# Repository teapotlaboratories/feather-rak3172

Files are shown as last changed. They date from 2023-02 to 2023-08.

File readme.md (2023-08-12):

# Teapotlabs Feather RAK3172
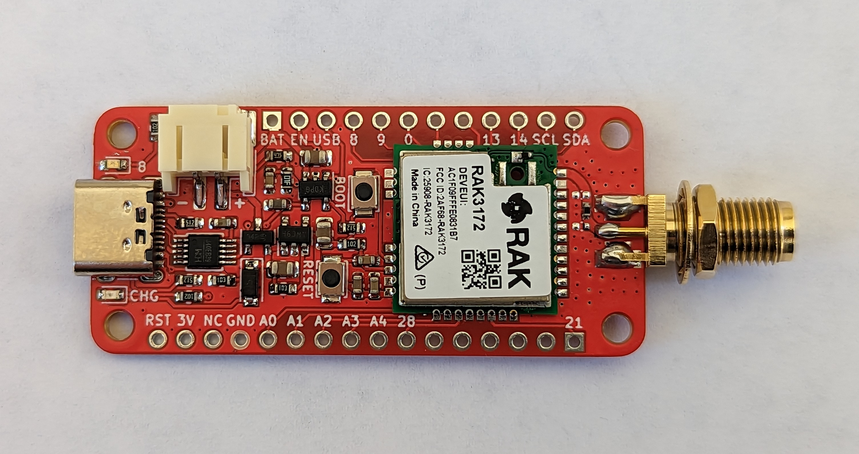
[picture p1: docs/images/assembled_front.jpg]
 
 
Teapotlabs Feather RAK3172 a Low-cost, Low-power LoRaWAN development board that breaks out [RAKwireless RAK3172](https://docs.rakwireless.com/Product-Categories/WisDuo/RAK3172-Module/Datasheet) to an Adafruit Feather-compatible format.

Based on the RAK3172, a STM32WLE5CC based module with ARM Cortex M4 processor, 48 MHz and 3.3V logic. The chip has a 256K of flash and 64K of RAM. 
With low-power application in mind, the board is capable to be in sleep mode for as low as 11uA, it also has a built-in voltage divider to sense battery voltage and battery charger.

Teapotlabs Feather RAK3172 is heavily inspired by [Penguino STM32WL LoRa-E5](https://github.com/azerimaker/Penguino-STM32WL-LoRa-E5) and [BastWAN-WLE](https://github.com/ElectronicCats/BastWAN-WLE) projects!

## Specification

- [RAK3172](https://docs.rakwireless.com/Product-Categories/WisDuo/RAK3172-Module/Overview/): An STM32WLE5CC module
- 3.3V only power/pin. 
- Down to 11uA Deep-Sleep
- Switchable TX Power. 14 dBm or 22 dBm on 915MHz frequency
- Supports LoRaWAN 1.0.3
- USB-C for **Arduino** and  **Mbed OS/STM32Cube** programming
- SMA antenna connector 
- JST-PH 2-Pin Battery Connector
- Built-in LiPo Charger ( 200mA Charge Rate )
- Voltage-Divider for Battery Monitoring ( default: **disabled** )
- LED Indicator on pin 8 ( default: **disabled** )
- Compatible with many Adafruit FeatherWings
- Max 1A power output

## To-do
- Update assembly/TeapotFeatherRAK3172_Assembly.zip and docs file to Revision 9.1

## Schematics
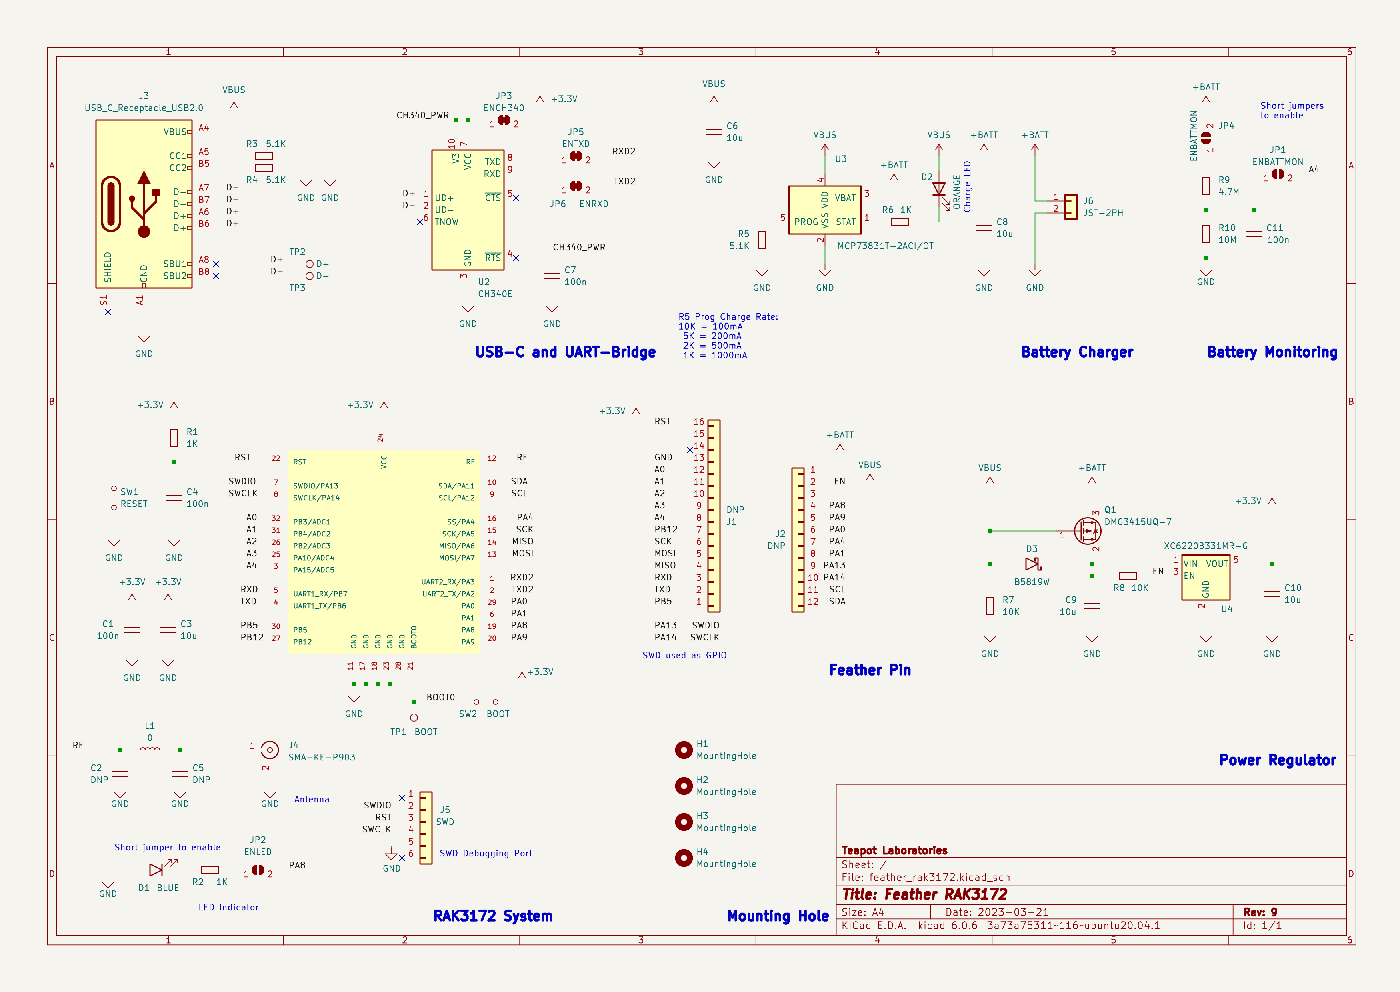
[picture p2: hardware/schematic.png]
schematic


### Jumper Definition
- JP1 and JP4: Enable/Disable Voltage Divider for Battery Sensing
- JP2: Enable/Disable LED Indicator on Pin 8
- JP3, JP5, and JP6: Enable/Disable UART Bridge

### Revision
- Revision 9  : First public release
- Revision 9.1: Fix LED D1 polarity 

### Pinout Diagram
> :warning: **The following pinout is not complete, please see STM32WLE5CC datasheet for more details.** 
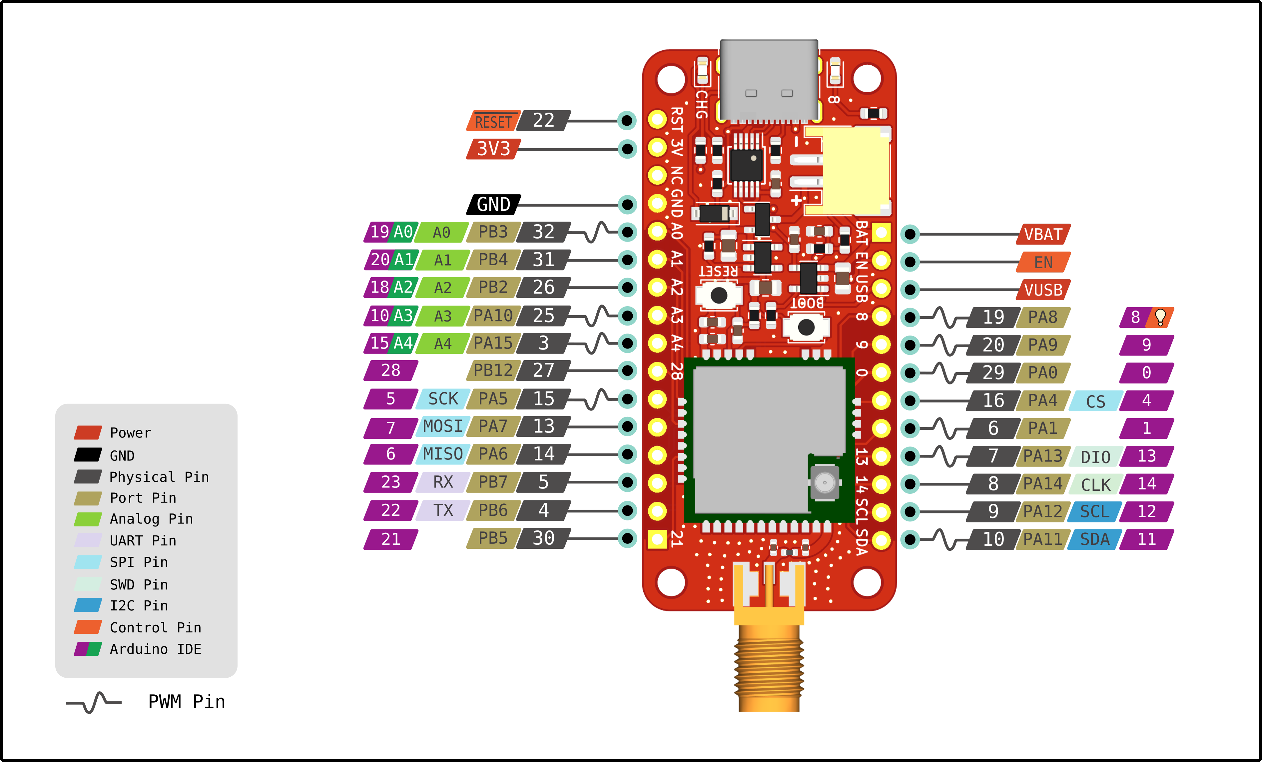
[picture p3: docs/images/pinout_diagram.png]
pinout_diagram


## Board
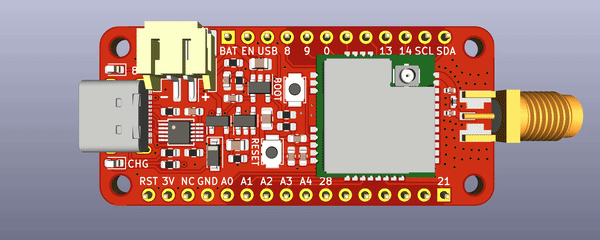
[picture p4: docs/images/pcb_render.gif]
pcb_render
<p align="center">  <br><b>PCB Render</b></p>

Built using KiCAD, the board is design to be as small as possible. The following design are based on the latest revision.
| Top Board | Bottom Board |
|--|--|
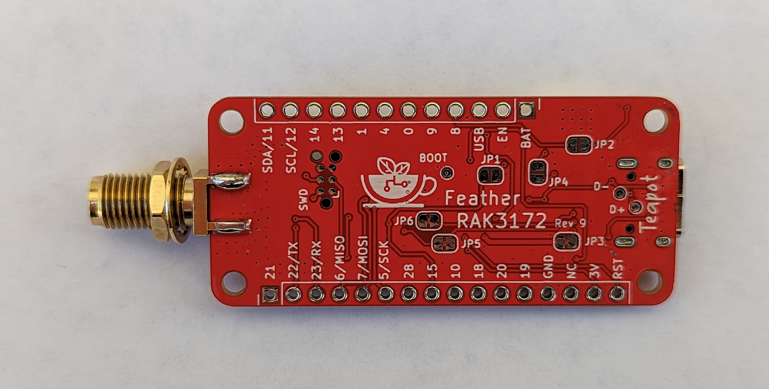
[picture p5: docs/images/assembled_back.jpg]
assembled_back
| <p align="center"> assembled_front</p> |  |
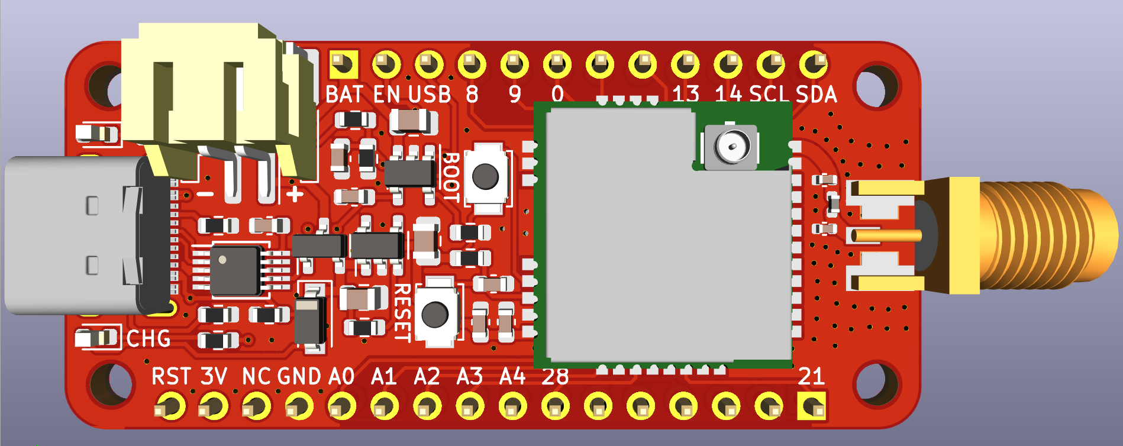
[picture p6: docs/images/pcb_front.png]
pcb_front
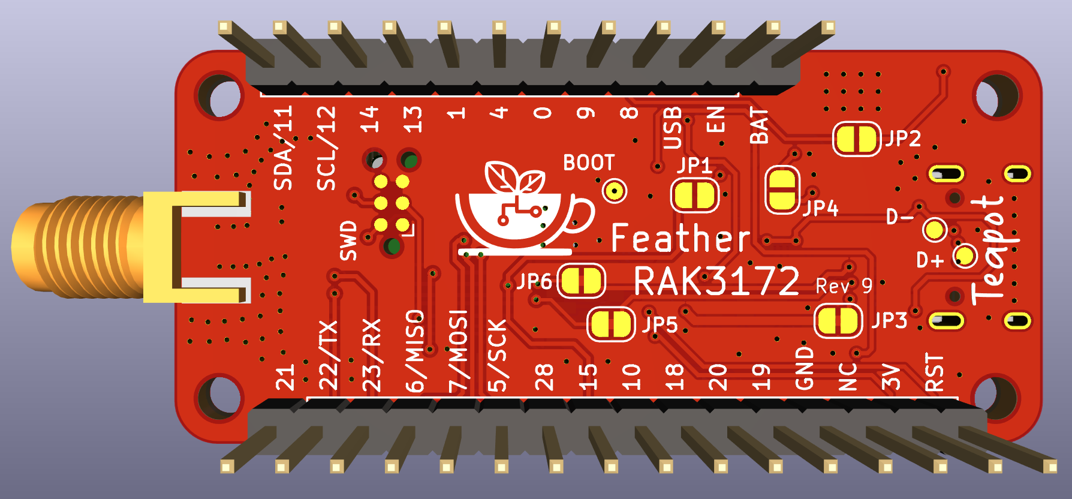
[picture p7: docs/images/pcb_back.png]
pcb_bottom
|  |  |

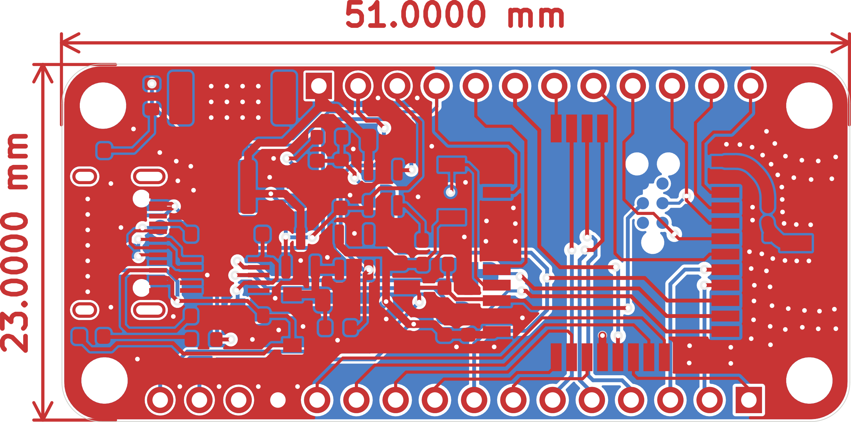
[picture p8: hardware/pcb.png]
pcb
 <p align="center"> <br><b>PCB Top and Bottom Layout</b></p> 
  
### Case
<p align="center">  case_render</p>

The case is design by [atmakers](https://www.thingiverse.com/atmakers/designs) with **Attribution-ShareAlike 3.0 Unported (CC BY-SA 3.0)** license.
The cases are 3D printable with any generic 3D printer with/without suppport (depends on the orientation). The STL files are available from authors download page  [here](https://www.thingiverse.com/thing:3212895) or from [this](https://github.com/teapotlaboratories/feather-rak3172/tree/main/hardware/case) repo.
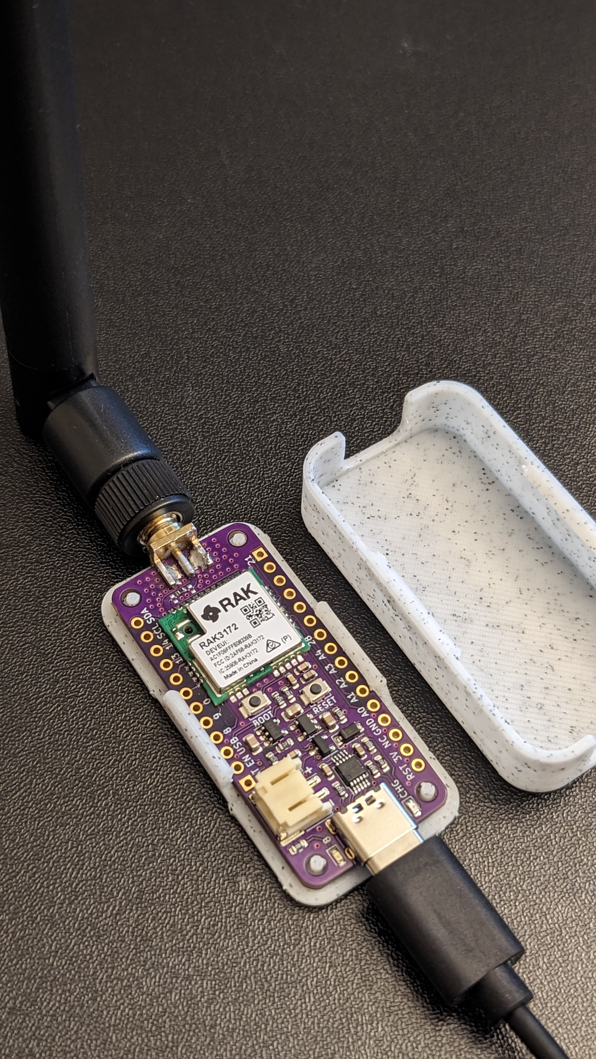
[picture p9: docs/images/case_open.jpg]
 <p align="center"><br><b>Case Open</b></p>
 
### Measurement
Power consumption measured using [Nordic PPK2](https://www.nordicsemi.com/Products/Development-hardware/Power-Profiler-Kit-2). The following are the summary of the measurement:
- Sleep and all jumper disabled (JP1 - JP6): **10.44 uA**
- Sleep and UART-Bridge enabled ( JP3, JP5, and JP6 ): **23.76 uA**
- Sleep, UART-Bridge and Battery Sense enabled ( JP1, and JP3 - JP6 ): **25.41 uA** 
- Transmit at 14 dBm: **40.45 mA**
- Transmit at 20 dBm: **100.38 mA**

More detailed measurement can be found [here](https://github.com/teapotlaboratories/feather-rak3172/tree/main/docs/measurement)

### Bill Of Materials
Most of the components are generic and can be bought from any electornics/semi-conductor distributor. RAK3172 is the only component available in [RAKwireless store](https://store.rakwireless.com/products/wisduo-lpwan-module-rak3172?variant=40014759493830). The bill of materials can be downloaded [here](https://github.com/teapotlaboratories/feather-rak3172/raw/main/hardware/bill_of_materials.csv)

> :warning: **Be sure to buy the RAK3172 variant without IPEX to use SMA connector** 

|Id|Designator|Quantity|Value|Footprint|
|:----|:----|:----|:----|:----|
|1|C11,C7,C4,C1|4|100n|0603_1608Metric|
|2|C6,C3|2|10u|0603_1608Metric|
|3|C9,C8,C10|3|10u|0805_2012Metric|
|4|D1|1|BLUE|0603_1608Metric|
|5|D2|1|ORANGE|0603_1608Metric|
|6|D3|1|B5819W|SOD-123|
|7|J3|1|U262-161N-4BVC11|USB_C_Receptacle_XKB_U262-16XN-4BVC11|
|8|J4|1|SMA-KE-P903|SMA-KE-P903|
|9|J6|1|S2B-PH-SM4-TB|JST_PH_S2B-PH-SM4-TB_1x02-1MP_P2.00mm_Horizontal|
|10|L1|1|0|0402_1005Metric|
|11|Q1|1|DMG3415UQ-7|SOT-23|
|12|R10|1|10M|0603_1608Metric|
|13|R2,R6,R1|3|1k|0603_1608Metric|
|14|R3,R5,R4|3|5.1k|0603_1608Metric|
|15|R7,R8|2|10k|0603_1608Metric|
|16|R9|1|4.7M|0603_1608Metric|
|17|SW1|1|B3U-1000P|SW_SPST_B3U-1000P|
|18|SW2|1|B3U-1000P|SW_SPST_B3U-1000P|
|19|U1|1|RAK3172|RAK3172|
|20|U2|1|CH340E|MSOP-10_3x3mm_P0.5mm|
|21|U3|1|MCP73831T-2ACI/OT|SOT-23-5|
|22|U4|1|XC6220B331MR-G|SOT-23-5|
|23|C5,C2|2|DNP|0402_1005Metric|
|24|J2|1|DNP|PinHeader_1x12_P2.54mm_Vertical|
|25|J1|1|DNP|PinHeader_1x16_P2.54mm_Vertical|

## Programming

By default, programming the device can be done over  the **USB-C**. Internally, the USB-C connects to the UART-Bridge that connects to the **UART2** port of the RAK3172. Out of the factory, the RAK3172 chip ships with an **AT firmware** that can be tested by sending AT command via the USB-C.

Using the USB-C, user can program the board using the **Arduino** or **MbedOS/STM32Cube** SDK.
The following are some very good tutorial to start developing with the device:
 - [Communicating with the AT firmware](https://docs.rakwireless.com/Product-Categories/WisDuo/RAK3172-Module/Quickstart/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)
 - [Programming with Arduino](https://docs.rakwireless.com/Product-Categories/WisDuo/RAK3172-Module/Quickstart/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)
 - [Programming with STM32Cube](https://docs.rakwireless.com/Product-Categories/WisDuo/RAK3172-Module/Low-Level-Development/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)
	 - RAKDAP1 is not needed. Before connecting to **STM32CubeProgrammer**, hold `BOOT` and press `RESET` on the board, to boot to UART bootloader of the RAK3172. After `RESET` button is pressed, `BOOT` button can be released, and the board should be able to connect to the **STM32CubeProgrammer**
 - [Programming with MbedOS](https://github.com/hallard/LoRa-E5-Tiny/blob/main/README.md#compile-and-flash-firmware)
	 - Programming the board can be done **without** using the ST-LINK, it should be simillar to [Programming with STM32Cube](https://docs.rakwireless.com/Product-Categories/WisDuo/RAK3172-Module/Low-Level-Development/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) process.

## Example Project
Teapotlabs Feather RAK3172 is a feather compatible board, and hence is compatible with the many available FeatherWing. The following are some example project that uses FeatherWings.

### Over-engineered Clock 
An over-engineered clock with main purpose to showcase FeatherWings compatibility.
FeatherWings and sensors used:  
- [Ultimate GPS](adafruit.com/product/3133)  
- [Tri-Color E-Ink](adafruit.com/product/4814)  
- [Qwiic Shield](sparkfun.com/products/16790)  
- [BME680](adafruit.com/product/3660)  
- [Modified E-Ink Case](learn.adafruit.com/eink-featherwing-display-stand)

<p align="center">
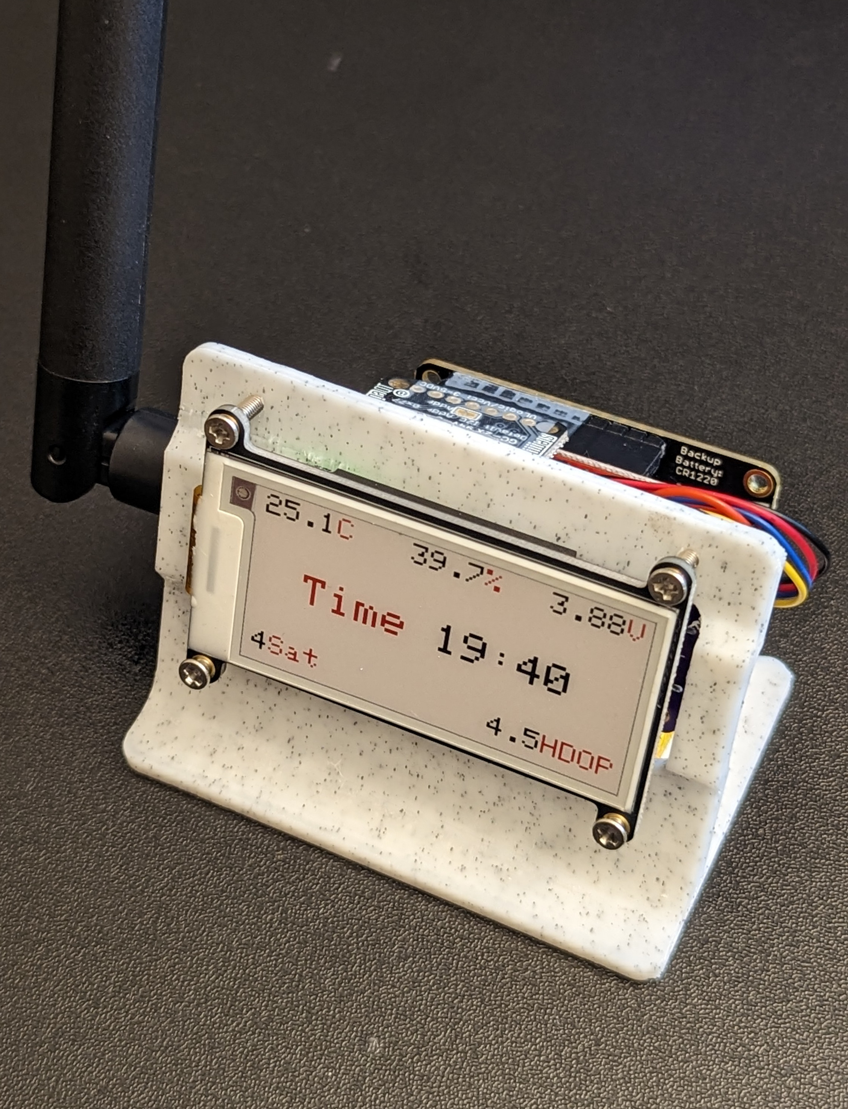
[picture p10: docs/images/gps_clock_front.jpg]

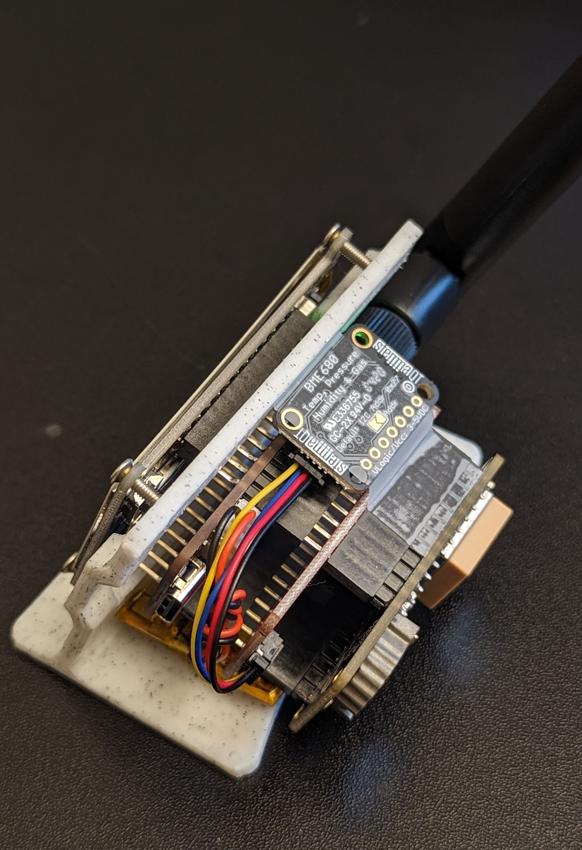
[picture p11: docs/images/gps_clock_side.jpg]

<br><b>Front and Side View</b></p>

<p align="center">  
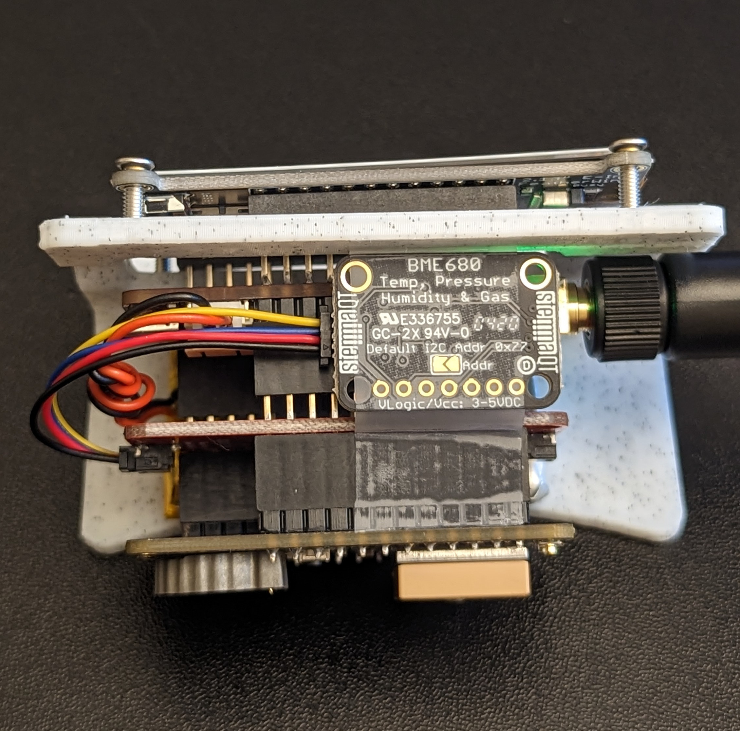
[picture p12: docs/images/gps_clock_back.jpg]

<br><b>Back View</b>
</p>
 
## Reference
The project won't be possible without the amazing work from people across the globe. The following are the reference to those awesome projects:

 - [Adafruit Feather RP2040](https://github.com/adafruit/Adafruit-Feather-RP2040-PCB)
 - [Penguino STM32WL LoRa-E5](https://github.com/azerimaker/Penguino-STM32WL-LoRa-E5)
 - [BastWAN-WLE](https://github.com/ElectronicCats/BastWAN-WLE)

## License
The product is open-source! However, some part of library used under **src**, might have it's own license.
Please reach out or create a ticket to report any license violation.



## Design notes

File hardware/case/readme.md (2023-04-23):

# License
The case are design by [atmakers](https://www.thingiverse.com/atmakers/designs) with **Attribution-ShareAlike 3.0 Unported (CC BY-SA 3.0)** license.
Original link: https://www.thingiverse.com/thing:3212895



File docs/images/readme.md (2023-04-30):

# Images

## Assembled Back


## Assembled Back Purple
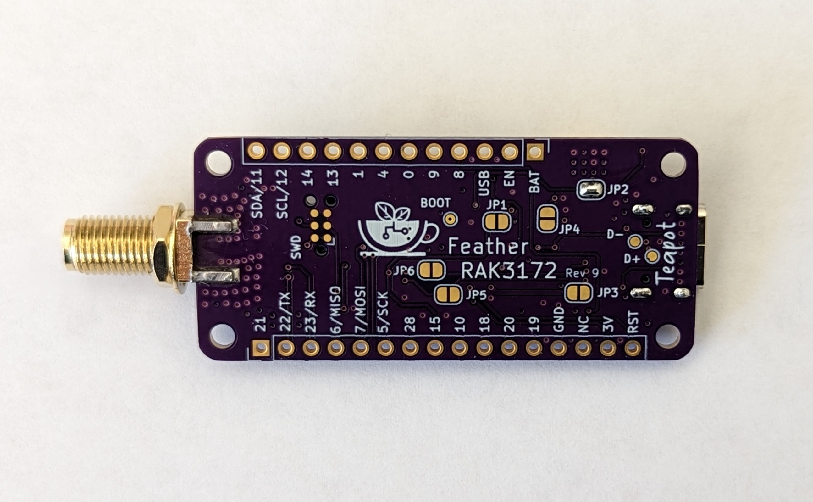
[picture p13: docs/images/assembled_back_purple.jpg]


## Assembled Front


## Assembled Front Purple
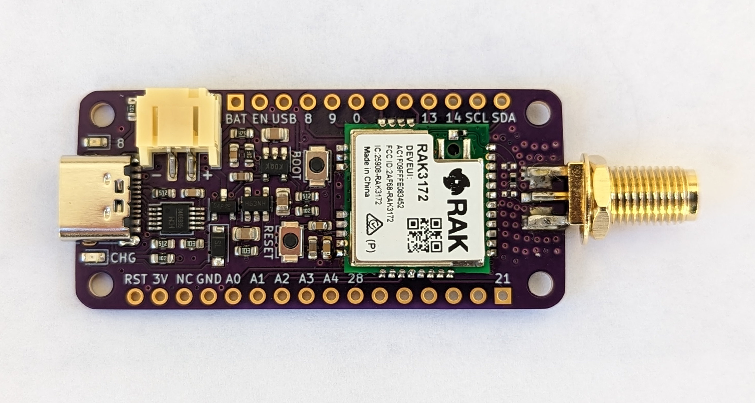
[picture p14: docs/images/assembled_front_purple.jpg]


## Case Close
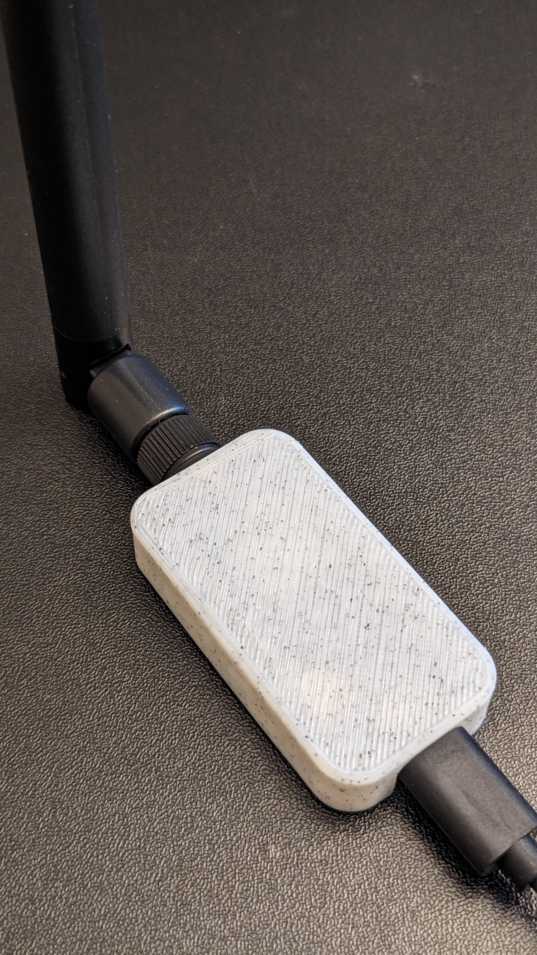
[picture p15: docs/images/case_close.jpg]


## Case Open


## Case Render


## GPS Clock Back


## GPS Clock Front


## GPS Clock Side


## PCB Back


## PCB Front


## PCB Front Orthographic
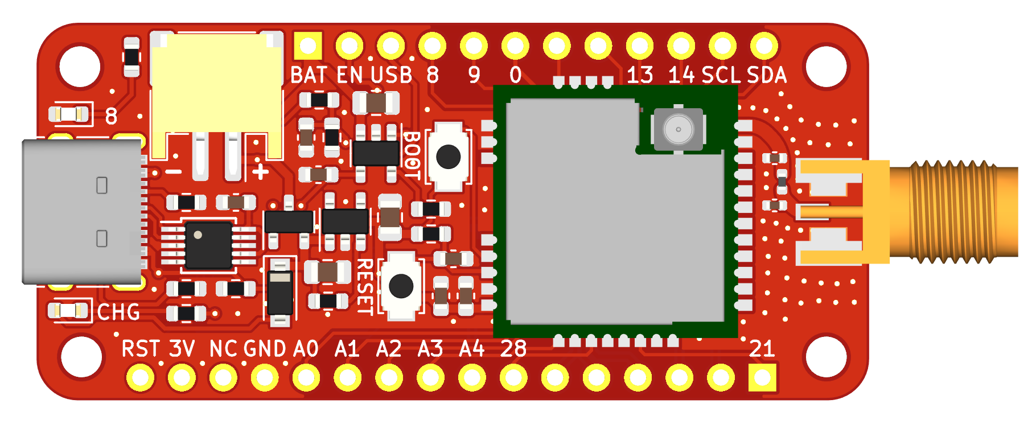
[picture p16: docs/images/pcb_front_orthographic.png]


## PCB Render


## Pinout Diagram


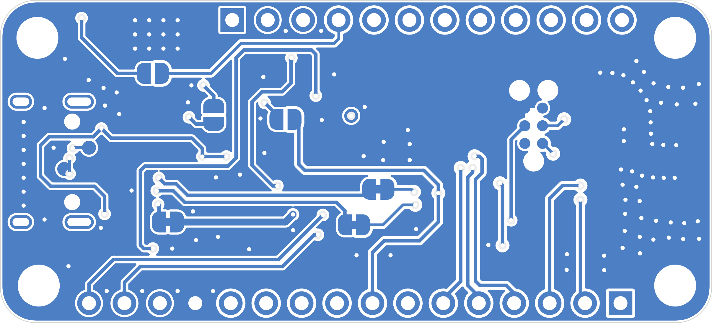
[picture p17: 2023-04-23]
hardware/pcb_bottom.png

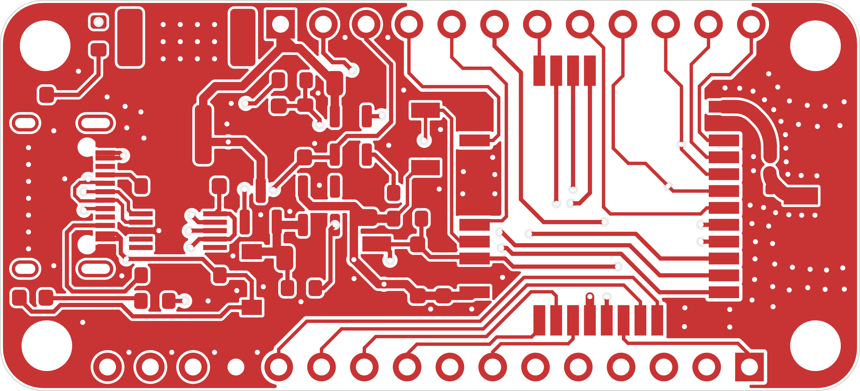
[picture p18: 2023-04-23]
hardware/pcb_top.png

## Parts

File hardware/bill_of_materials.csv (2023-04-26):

Id | Designator | Quantity | Manufacturer | Manufacturer Part Number | Value | Description | Footprint | Type | Distributor | Distributor Part Number | Distributor Link
1 | C11,C7,C4,C1 | 4 | YAGEO | CC0603KRX7R6BB104 | 100n | Ceramic Capacitor 100n 10% 10V X7R | 0603_1608Metric | SMD | LCSC | C519438 | https://www.lcsc.com/product-detail/_YAGEO-_C519438.html
2 | C6,C3 | 2 | Samsung Electro-Mechanics | CL10A106KP8NNNC | 10u | Ceramic Capacitor 10u 10% 10V X5R | 0603_1608Metric | SMD | LCSC | C19702 | https://www.lcsc.com/product-detail/_Samsung-Electro-Mechanics-_C19702.html
3 | C9,C8,C10 | 3 | Samsung Electro-Mechanics | CL21A106KPFNNNE | 10u | Ceramic Capacitor 10u 10% 10V X5R | 0805_2012Metric | SMD | LCSC | C17024 | https://www.lcsc.com/product-detail/_Samsung-Electro-Mechanics-_C17024.html
4 | D1 | 1 | Everlight Elec | 19-217/BHC-ZL1M2RY/3T | BLUE | LED Blue 2V 25mA | 0603_1608Metric | SMD | LCSC | C72041 | https://www.lcsc.com/product-detail/_Everlight-Elec-_C72041.html
5 | D2 | 1 | EKINGLUX | E6C0603SEAC1UDA | ORANGE | LED Orange 2V 25mA | 0603_1608Metric | SMD | LCSC | C375450 | https://www.lcsc.com/product-detail/_EKINGLUX-_C375450.html
6 | D3 | 1 | GOODWORK | B5819W | B5819W | Schottky Barrier Diodes (SBD) 40V 0.58V@1A | SOD-123 | SMD | LCSC | C2943878 | https://www.lcsc.com/product-detail/_GOODWORK-_C2943878.html
7 | J3 | 1 | XKB Connectivity | U262-161N-4BVC11 | U262-161N-4BVC11 | USB Type C Receptacle | USB_C_Receptacle_XKB_U262-16XN-4BVC11 | SMD | LCSC | C319148 | https://www.lcsc.com/product-detail/_XKB-Connectivity-_C319148.html
8 | J4 | 1 | DreamLNK | SMA-KE-P903 | SMA-KE-P903 | SMA RF Connectors Board Edge 50Ω 5.35mm 915MHz | SMA-KE-P903 | Through-Hole | LCSC | C914558 | https://www.lcsc.com/product-detail/_DreamLNK-_C914558.html
9 | J6 | 1 | JST Sales America Inc. | S2B-PH-SM4-TB(LF)(SN) | S2B-PH-SM4-TB | Connector Header Right Angle 2 position 0.079" (2.00mm) | JST_PH_S2B-PH-SM4-TB_1x02-1MP_P2.00mm_Horizontal | SMD | LCSC | C295747 | https://www.lcsc.com/product-detail/Wire-To-Board-Wire-To-Wire-Connector_JST-Sales-America-S2B-PH-SM4-TB-LF-SN_C295747.html
10 | L1 | 1 | YAGEO | RC0402JR-070RL | 0 | Resistor 0 5% 65mW | 0402_1005Metric | SMD | LCSC | C60485 | https://www.lcsc.com/product-detail/_YAGEO-_C60485.html
11 | Q1 | 1 | Diodes Incorporated | DMG3415UQ-7 | DMG3415UQ-7 | MOSFET P-Channel 20V 4A 39mΩ@4.5V | SOT-23 | SMD | LCSC | C459537 | https://www.lcsc.com/product-detail/_Diodes-Incorporated-_C459537.html
12 | R10 | 1 | UNI-ROYAL(Uniroyal Elec) | 0603WAF1005T5E | 10M | Resistor 10M 1% 100mW | 0603_1608Metric | SMD | LCSC | C7250 | https://www.lcsc.com/product-detail/_UNI-ROYAL-Uniroyal-Elec-_C7250.html
13 | R2,R6,R1 | 3 | FOJAN | FRC0603J102 TS | 1k | Resistor 1k 5% 100mW | 0603_1608Metric | SMD | LCSC | C2907113 | https://www.lcsc.com/product-detail/_FOJAN-_C2907113.html
14 | R3,R5,R4 | 3 | YAGEO | RC0603FR-075K1L | 5.1k | Resistor 5.1k 1% 100mW | 0603_1608Metric | SMD | LCSC | C105580 | https://www.lcsc.com/product-detail/_YAGEO-_C105580.html
15 | R7,R8 | 2 | YAGEO | RC0603JR-0710KL | 10k | Resistor 10k 5% 100mW | 0603_1608Metric | SMD | LCSC | C99198 | https://www.lcsc.com/product-detail/_YAGEO-_C99198.html
16 | R9 | 1 | UNI-ROYAL(Uniroyal Elec) | 0603WAF4704T5E | 4.7M | Resistor 4.7M 1% 100mW | 0603_1608Metric | SMD | LCSC | C23163 | https://www.lcsc.com/product-detail/_UNI-ROYAL-Uniroyal-Elec-_C23163.html
17 | SW1 | 1 | Omron Electronics | B3U-1000P | B3U-1000P | Tactile Switches SPST 50mA 12V 2.5x3mm | SW_SPST_B3U-1000P | SMD | LCSC | C231329 | https://www.lcsc.com/product-detail/_Omron-Electronics-_C231329.html
18 | SW2 | 1 | Omron Electronics | B3U-1000P | B3U-1000P | Tactile Switches SPST 50mA 12V 2.5x3mm | SW_SPST_B3U-1000P | SMD | LCSC | C231329 | https://www.lcsc.com/product-detail/_Omron-Electronics-_C231329.html
19 | U1 | 1 | RAKwireless | RAK3172 | RAK3172 | RAK3172 Module without IPEX AS923 | RAK3172 | SMD | RAKwireless | 309044 | Contact inquiry@rakwireless.com for SKU: 309044
20 | U2 | 1 | WCH(Jiangsu Qin Heng) | CH340E | CH340E | USB to UART IC 2Mbps Transceiver USB 2.0 | MSOP-10_3x3mm_P0.5mm | SMD | LCSC | C99652 | https://www.lcsc.com/product-detail/_WCH-Jiangsu-Qin-Heng-_C99652.html
21 | U3 | 1 | Microchip Technology | MCP73831T-2ACI/OT | MCP73831T-2ACI/OT | Charger IC Lithium Ion/Polymer | SOT-23-5 | SMD | LCSC | C424093 | https://www.lcsc.com/product-detail/Battery-Management-ICs_Microchip-Tech-MCP73831T-2ACI-OT_C424093.html
22 | U4 | 1 | Torex Semiconductor | XC6220B331MR-G | XC6220B331MR-G | Linear Voltage Regulators (LDO) 1A Fixed +3.3V | SOT-23-5 | SMD | LCSC | C86534 | https://www.lcsc.com/product-detail/_Torex-Semicon-_C86534.html
23 | C5,C2 | 2 | - | - | DNP | Do Not Populate | 0402_1005Metric | DNP | - | - | -
24 | J2 | 1 | - | - | DNP | Do Not Populate | PinHeader_1x12_P2.54mm_Vertical | DNP | - | - | -
25 | J1 | 1 | - | - | DNP | Do Not Populate | PinHeader_1x16_P2.54mm_Vertical | DNP | - | - | -

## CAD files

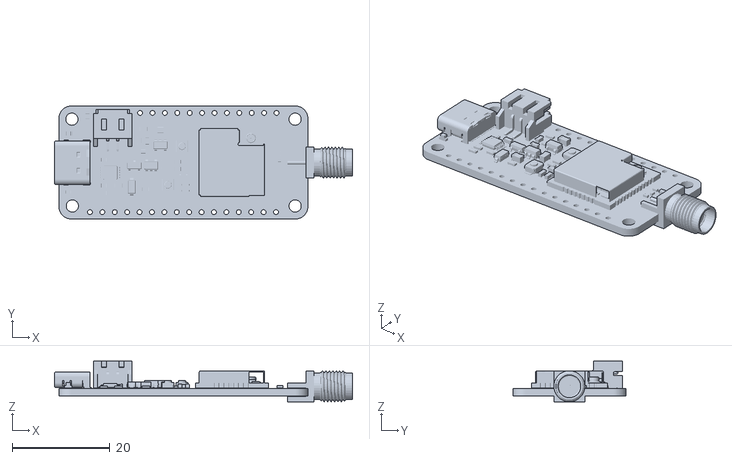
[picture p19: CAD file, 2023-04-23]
docs/assembeld_board.stl
61.0 x 23.1 x 8.30

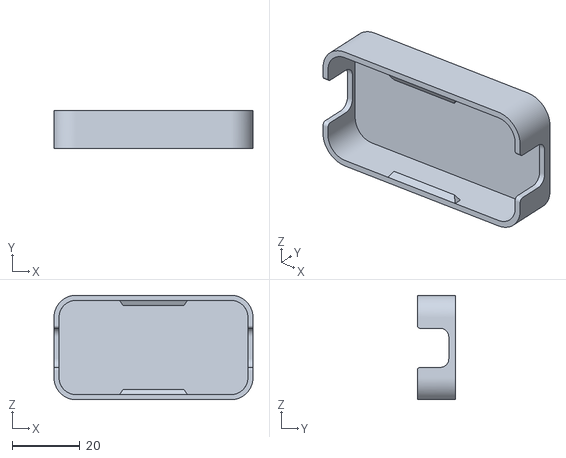
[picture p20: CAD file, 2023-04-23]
hardware/case/top.stl
58.8 x 11.4 x 30.9

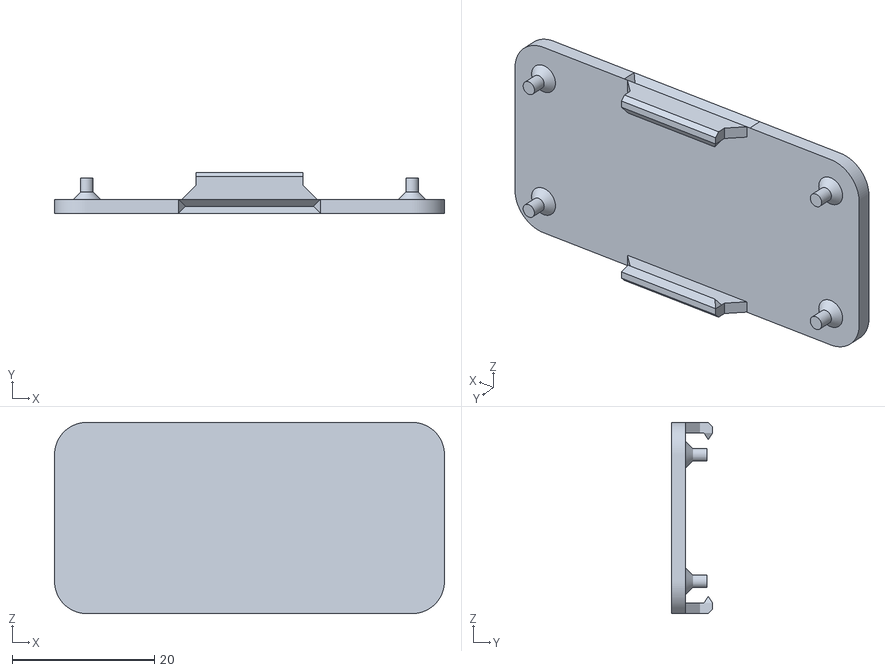
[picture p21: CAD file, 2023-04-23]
hardware/case/bottom.stl
54.8 x 5.77 x 26.9

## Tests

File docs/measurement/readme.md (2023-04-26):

# Measurement
Power consumption measured using [Nordic PPK2](https://www.nordicsemi.com/Products/Development-hardware/Power-Profiler-Kit-2). The following are the summary of the measurement:
- Sleep and all jumper disabled (JP1 - JP6): **10.44 uA**
- Sleep and UART-Bridge enabled ( JP3, JP5, and JP6 ): **23.76 uA**
- Sleep, UART-Bridge and Battery Sense enabled ( JP1, and JP3 - JP6 ): **25.41 uA** 
- Transmit at 14 dBm: **40.45 mA**
- Transmit at 20 dBm: **100.38 mA**

## Sleep and all jumper disabled
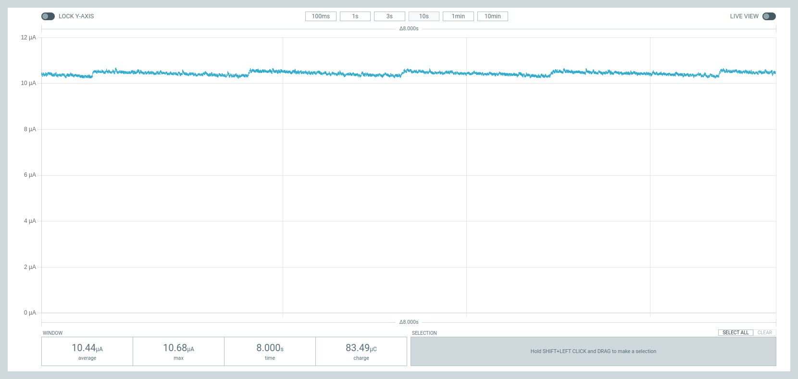
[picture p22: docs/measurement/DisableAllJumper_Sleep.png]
disable_all_jumper_sleep


## Sleep, Enable UART Bridge
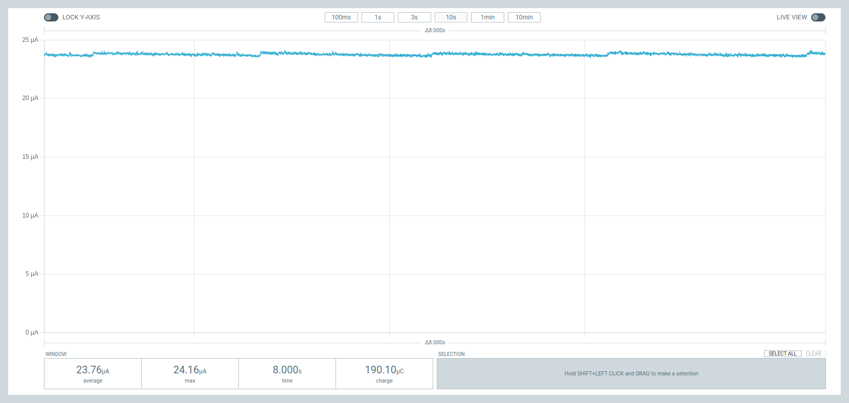
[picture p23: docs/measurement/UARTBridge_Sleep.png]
uart_bridge_sleep


## Sleep, Enable UART Bridge and Battery Sense
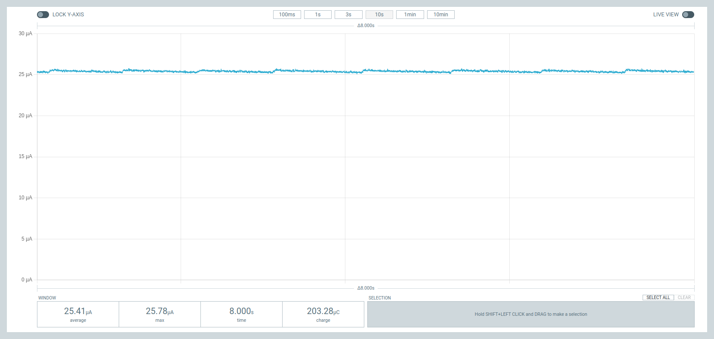
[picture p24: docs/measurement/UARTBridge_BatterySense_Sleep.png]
uart_bridge_battery_sense_sleep


## Transmit at 14 dBm
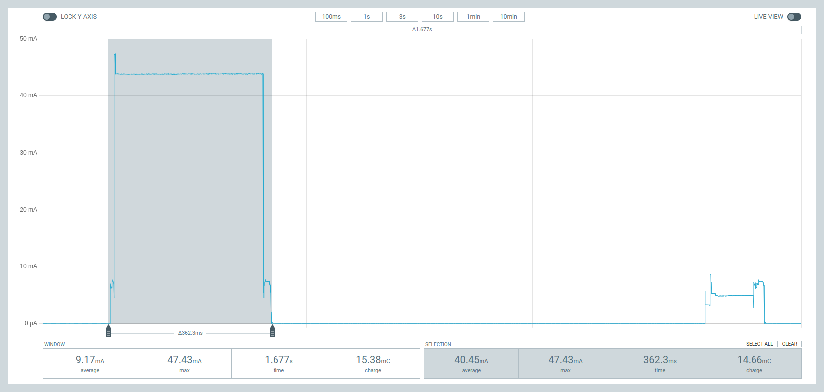
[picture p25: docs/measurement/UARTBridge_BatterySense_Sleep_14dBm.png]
uart_bridge_battery_sense_sleep_14dbm


## Transmit at 20 dBm
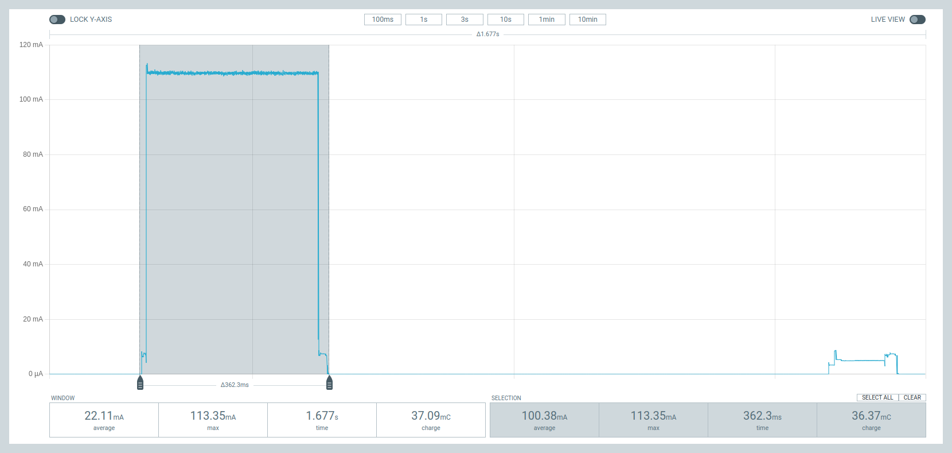
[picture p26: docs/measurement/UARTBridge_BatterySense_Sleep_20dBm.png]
uart_bridge_battery_sense_sleep_20dbm


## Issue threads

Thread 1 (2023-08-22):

Polarity of D1 LED in schematic

jmeckstroth, 2023-08-22:
Is not the polarity of D1 shown incorrect on the schematic?

jmeckstroth, 2023-08-22:
Please update the Shared Project files in PCBWAY to correct the D1 LED polarity.  Thanks!

aldwinhermanudin, 2023-08-23:
Hi @jmeckstroth ,

Thanks for raising the issue.
I'll update it next week, as I'm currently away from my computer. Thanks!

jmeckstroth, 2023-09-26:
FYI,  the Teapot Feather boards with a US915 version of the RAK3172 that I procured from PCBWAY function fine.  I am considering a variant of the Teapot board that brings TX2/RX2 to the Feather pins instead of TX1/RX1, in order to use the module with another MCU using the AT Command means of controlling the RAK3172.

aldwinhermanudin, 2023-09-26:
Thanks, glad to hear it works.
Now that I think of it, that's a good idea.

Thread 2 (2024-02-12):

No issue, just ask about picture

NamNamIoT, 2024-02-12:
Hello, I am very impressed with your product.
I would like to know which created the photo that depicts the pinout.
What software was it created with?

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

Thank you very much bro!

aldwinhermanudin, 2024-02-13:
Hi @NamNamIoT,

Thanks! Honestly it's a little bit manual.

- Top Board: From KiCAD ( there's a Orthographic Projection option in the 3D PCB Viewer )
- Pin Legend and Name: https://github.com/ATMakersOrg/HoldingArea/blob/master/FeatherTemplate.svg
- I use Inkscape to combine those together.

You can see tutorial [here](https://blog.adafruit.com/2019/07/11/automating-the-making-of-beautiful-pinout-diagrams-for-microcontroller-boards-documentation-at_makers/)

NamNamIoT, 2024-02-13:
Thank you verymuch pro!

Closed 2024-02-13.

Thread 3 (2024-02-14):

No issue, just ask schematic

NamNamIoT, 2024-02-14:
In case battery under 3.6V, with XC6220B331MR we still have 3.3V in output pro?

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

Closed 2024-02-14.

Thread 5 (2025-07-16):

Battery connector polarity reversed

thesoupdragon, 2025-07-16:
I have just had 5 PCBs made by JLPCB - and they are great. so first off, thank you!

I discovered that the battery connection (S2B-PH-SM4-TB) has the wrong polarity. when buying either premade battery connection wires with a connector attached, or an entire LiPo battery with pre-made connector wire, the "usual" polarity is reversed.  As you look from the top of the board the red +ve wire is on the right - but on the PCB the +ve trace is on the left.

If, like me, you connect a "normal" battery the board gets very hot, very quickly and would no doubt ruin it if I had not smelled it getting very hot.

thanks

Tony

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

aldwinhermanudin, 2025-08-03:
Hi @thesoupdragon,

Thank you for trying it out! and My apologies for the late reply, just got back from a family vacation.

Yeah, I reference my design from batteries sold in Adafruit such as the https://www.adafruit.com/product/258, which has the correct polarity.

Unfortunately, that JST connection is a generic port so there's no standard on which + or - is located.

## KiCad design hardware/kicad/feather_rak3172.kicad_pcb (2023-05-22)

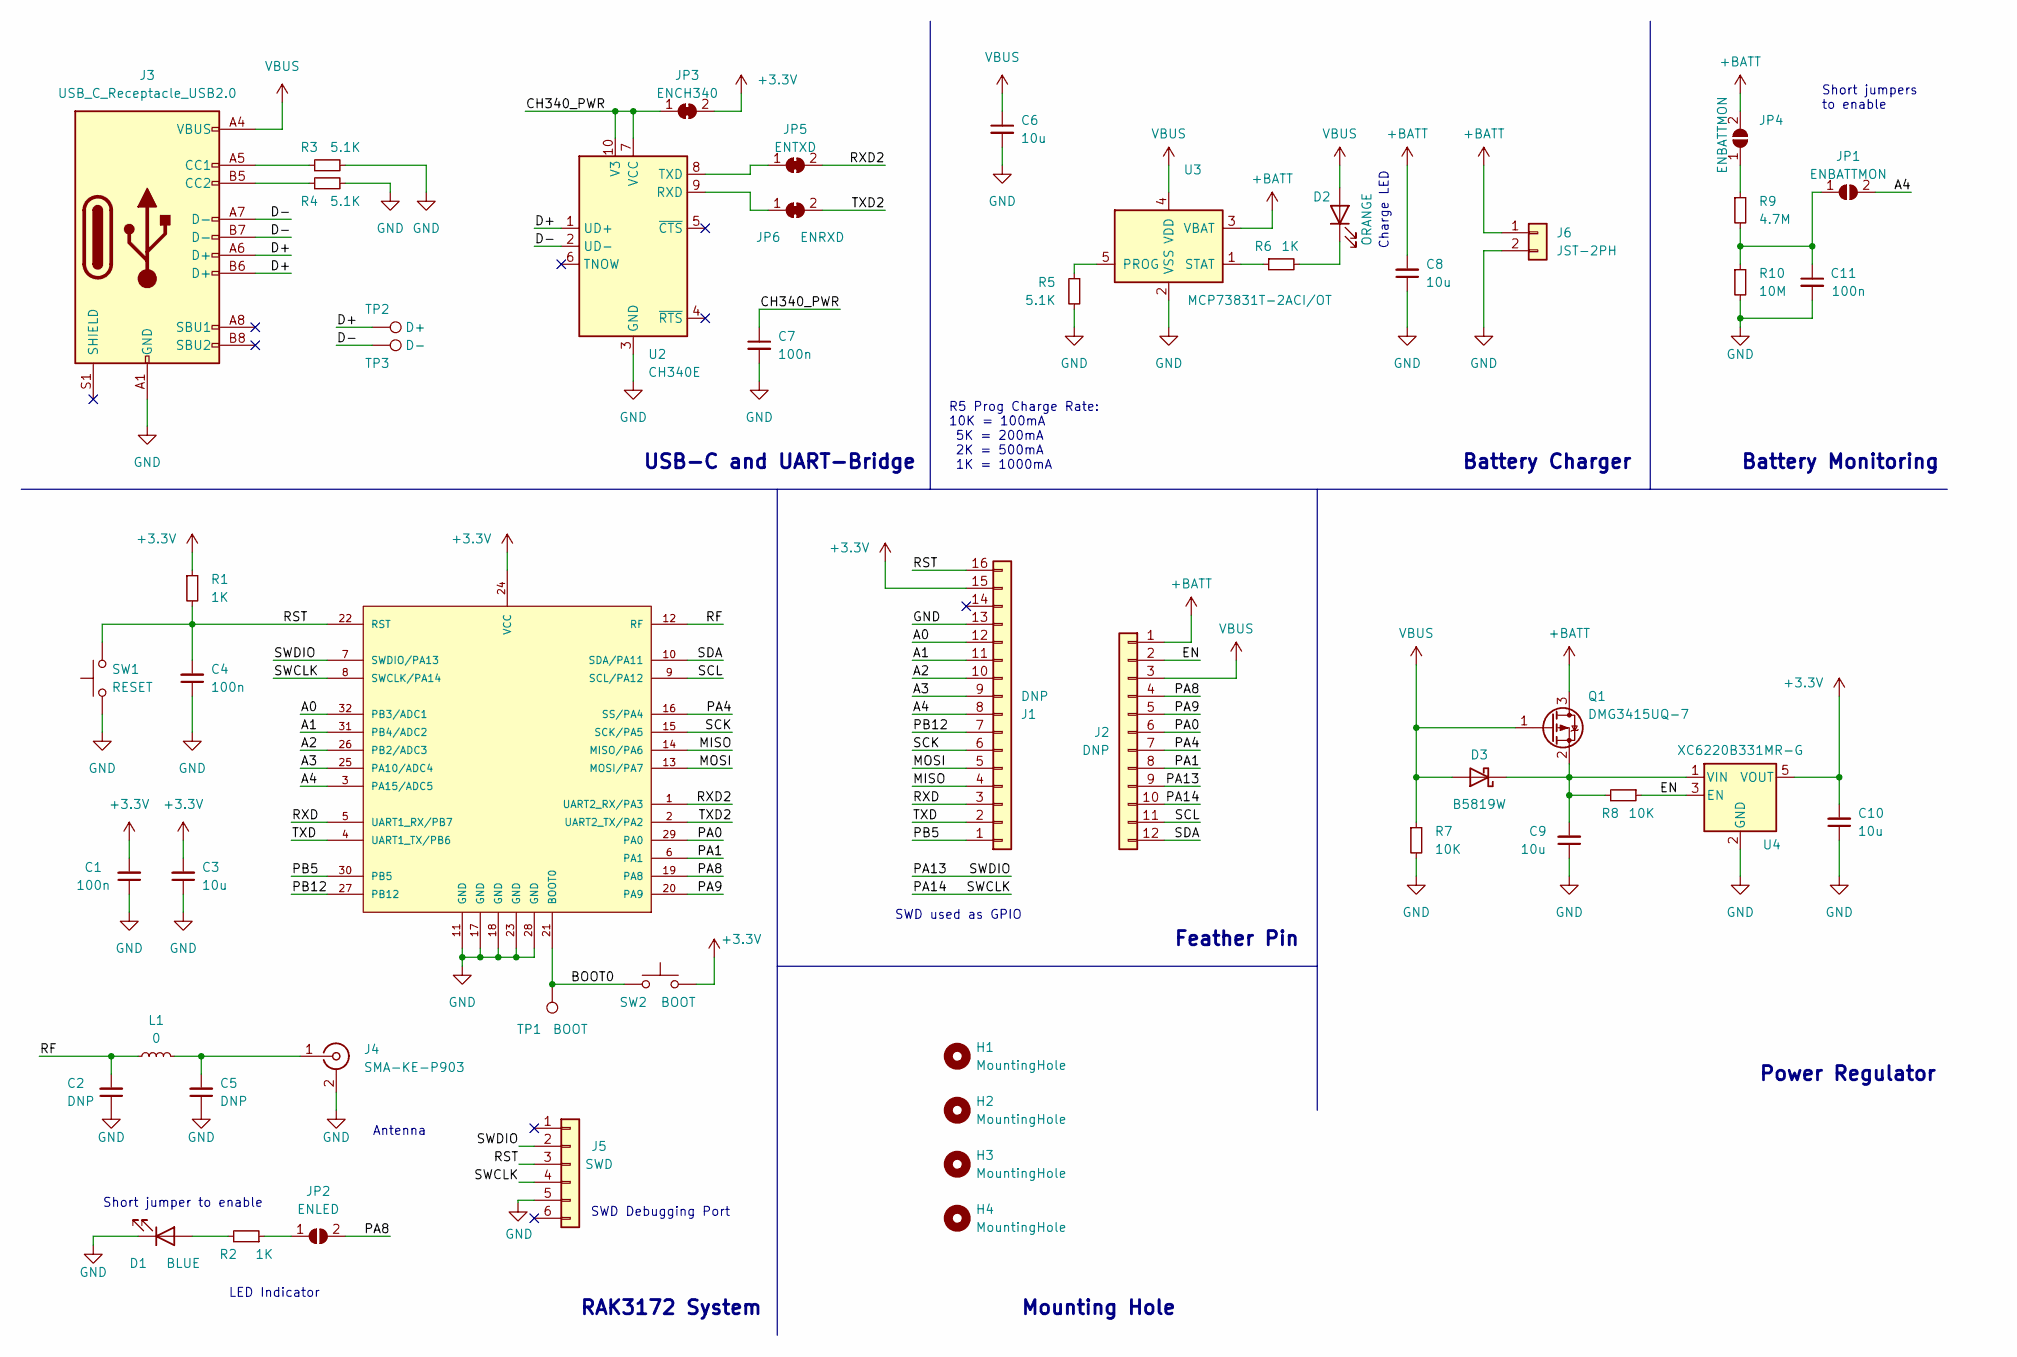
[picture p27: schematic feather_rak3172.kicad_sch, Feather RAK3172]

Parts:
C1, C4, C7, C11: 100n; C_0603_1608Metric; Part Description Ceramic Capacitor 100nF 10% 10V X7R
C2, C5: DNP; C_0402_1005Metric
C3, C6: 10u; C_0603_1608Metric; Part Description Ceramic Capacitor 10uF 10% 10V X5R
C8, C9, C10: 10u; C_0805_2012Metric; Part Description Ceramic Capacitor 10uF 10% 10V X5R
D1: BLUE; LED_0603_1608Metric; Part Description Blue 2V 25mA
D2: ORANGE; LED_0603_1608Metric; Part Number Orange 2V 25mA
D3: B5819W; D_SOD-123; Part Description 0.05mA@40V 0.58V@1A
H1, H2, H3, H4: MountingHole; MountingHole_2.5mm
J1: DNP; PinHeader_1x16_P2.54mm_Vertical
J2: DNP; PinHeader_1x12_P2.54mm_Vertical
J3: USB_C_Receptacle_USB2.0; USB_C_Receptacle_XKB_U262-16XN-4BVC11; Part Number U262-161N-4BVC11
J4: SMA-KE-P903; Part Number SMA-KE-P903
J5: SWD; Tag-Connect_TC2030-IDC-NL_2x03_P1.27mm_Vertical
J6: JST-2PH; JST_PH_S2B-PH-SM4-TB_1x02-1MP_P2.00mm_Horizontal; Part Number JST-PH S2B-PH-SM4-TB
JP1, JP4: ENBATTMON; SolderJumper-2_P1.3mm_Open_RoundedPad1.0x1.5mm
JP2: ENLED; SolderJumper-2_P1.3mm_Open_RoundedPad1.0x1.5mm
JP3: ENCH340; SolderJumper-2_P1.3mm_Bridged_RoundedPad1.0x1.5mm
JP5: ENTXD; SolderJumper-2_P1.3mm_Bridged_RoundedPad1.0x1.5mm
JP6: ENRXD; SolderJumper-2_P1.3mm_Bridged_RoundedPad1.0x1.5mm
L1: 0; L_0402_1005Metric
Q1: DMG3415UQ-7; SOT-23; Part Number DMG3415UQ-7
R1, R2, R6: 1K; R_0603_1608Metric; Part Description Resistor 1k 5% 100mW
R3, R4: 5.1K; R_0603_1608Metric; Part Description Resistor 5.1K 1% 100mW
R5: 5.1K; R_0603_1608Metric; Part Description Resistor 5.1k 1% 100mW
R7, R8: 10K; R_0603_1608Metric; Part Description Resistor 10k 5% 100mW
R9: 4.7M; R_0603_1608Metric; Part Description Resistor 4.7M 1% 100mW
R10: 10M; R_0603_1608Metric; Part Description Resistor 10M 1% 100mW
SW1: RESET; SW_SPST_B3U-1000P; Part Number B3U-1000P
SW2: BOOT; SW_SPST_B3U-1000P; Part Number B3U-1000P
TP1: BOOT; TestPoint_Pad_D1.0mm
TP2: D+; TestPoint_Pad_D1.0mm
TP3: D-; TestPoint_Pad_D1.0mm
U1: RAK3172; Part Number RAK3172
U2: CH340E; MSOP-10_3x3mm_P0.5mm; Part Number CH340E
U3: MCP73831T-2ACI/OT; SOT-23-5; Part Number MCP73831T-2ACI/OT
U4: XC6220B331MR-G; SOT-23-5; Part Number XC6220B331MR-G

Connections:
+3.3V: C1.2, C3.2, C10.2, J1.15, JP3.2 (B), R1.1, SW2.1, U1.24 (VCC), U4.5 (VOUT)
+BATT: C8.2, J2.1, J6.1, JP4.2 (B), Q1.3 (D), U3.3 (VBAT)
/A0: J1.12, U1.32 (PB3/ADC1)
/A1: J1.11, U1.31 (PB4/ADC2)
/A2: J1.10, U1.26 (PB2/ADC3)
/A3: J1.9, U1.25 (PA10/ADC4)
/A4: J1.8, JP1.2 (B), U1.3 (PA15/ADC5)
/BOOT0: SW2.2, TP1.1, U1.21 (BOOT0)
/CH340_PWR: C7.1, JP3.1 (A), U2.7 (VCC), U2.10 (V3)
/D+: J3.A6 (D+), J3.B6 (D+), TP2.1, U2.1 (UD+)
/D-: J3.A7 (D-), J3.B7 (D-), TP3.1, U2.2 (UD-)
/EN: J2.2, R8.1, U4.3 (EN)
/MISO: J1.4, U1.14 (MISO/PA6)
/MOSI: J1.5, U1.13 (MOSI/PA7)
/PA0: J2.6, U1.29 (PA0)
/PA1: J2.8, U1.6 (PA1)
/PA4: J2.7, U1.16 (SS/PA4)
/PA8: J2.4, JP2.2 (B), U1.19 (PA8)
/PA9: J2.5, U1.20 (PA9)
/PA13: J2.9, J5.2, U1.7 (SWDIO/PA13)
/PA14: J2.10, J5.4, U1.8 (SWCLK/PA14)
/PB5: J1.1, U1.30 (PB5)
/PB12: J1.7, U1.27 (PB12)
/RF: C2.2, L1.1, U1.12 (RF)
/RST: C4.2, J1.16, J5.3, R1.2, SW1.2, U1.22 (RST)
/RXD: J1.3, U1.5 (UART1_RX/PB7)
/RXD2: JP5.2 (B), U1.1 (UART2_RX/PA3)
/SCK: J1.6, U1.15 (SCK/PA5)
/SCL: J2.11, U1.9 (SCL/PA12)
/SDA: J2.12, U1.10 (SDA/PA11)
/TXD: J1.2, U1.4 (UART1_TX/PB6)
/TXD2: JP6.2 (B), U1.2 (UART2_TX/PA2)
GND: C1.1, C2.1, C3.1, C4.1, C5.1, C6.2, C7.2, C8.1, C9.1, C10.1, C11.2, D1.1 (K), J1.13, J3.A1 (GND), J3.A12 (GND), J3.B1 (GND), J3.B12 (GND), J4.2 (Ext), J5.5, J6.2, R3.2, R4.2, R5.2, R7.2, R10.2, SW1.1, U1.11 (GND), U1.17 (GND), U1.18 (GND), U1.23 (GND), U1.28 (GND), U2.3 (GND), U3.2 (VSS), U4.2 (GND)
unnamed: C5.2, J4.1 (In), L1.2
unnamed: C9.2, D3.1 (K), Q1.2 (S), R8.2, U4.1 (VIN)
unnamed: C11.1, JP1.1 (A), R9.2, R10.1
unnamed: D2.1 (K), R6.2
unnamed: J3.A5 (CC1), R3.1
unnamed: J3.B5 (CC2), R4.1
unnamed: JP2.1 (A), R2.1
unnamed: JP4.1 (A), R9.1
unnamed: JP5.1 (A), U2.8 (TXD)
unnamed: JP6.1 (A), U2.9 (RXD)
unnamed: D1.2 (A), R2.2
unnamed: R5.1, U3.5 (PROG)
unnamed: R6.1, U3.1 (STAT)
VBUS: C6.1, D2.2 (A), D3.2 (A), J2.3, J3.A4 (VBUS), J3.A9 (VBUS), J3.B4 (VBUS), J3.B9 (VBUS), Q1.1 (G), R7.1, U3.4 (VDD)

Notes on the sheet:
Charge LED
Battery Monitoring
RAK3172 System
SWD used as GPIO
Mounting Hole
R5 Prog Charge Rate: 10K = 100mA 5K = 200mA 2K = 500mA 1K = 1000mA
Short jumpers to enable
Short jumper to enable
USB-C and UART-Bridge
SWD Debugging Port
LED Indicator
Antenna
Power Regulator
Battery Charger
Feather Pin

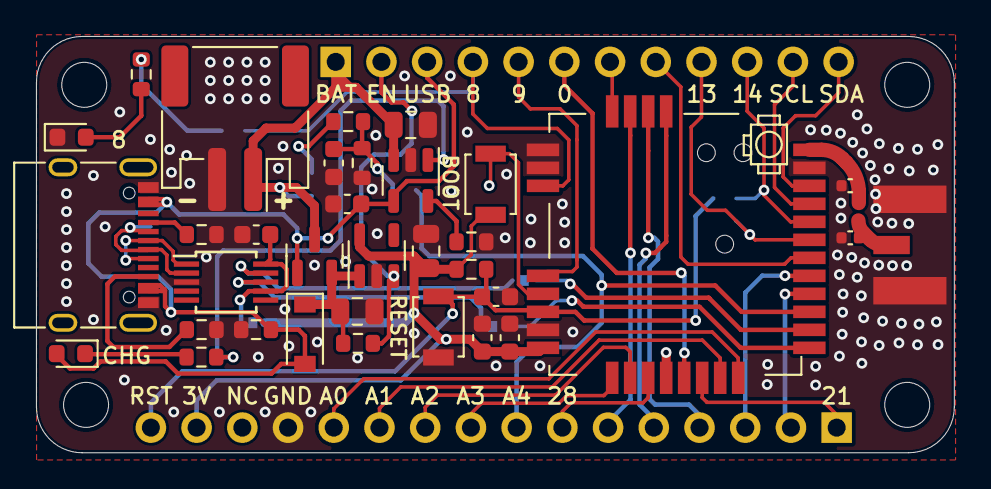
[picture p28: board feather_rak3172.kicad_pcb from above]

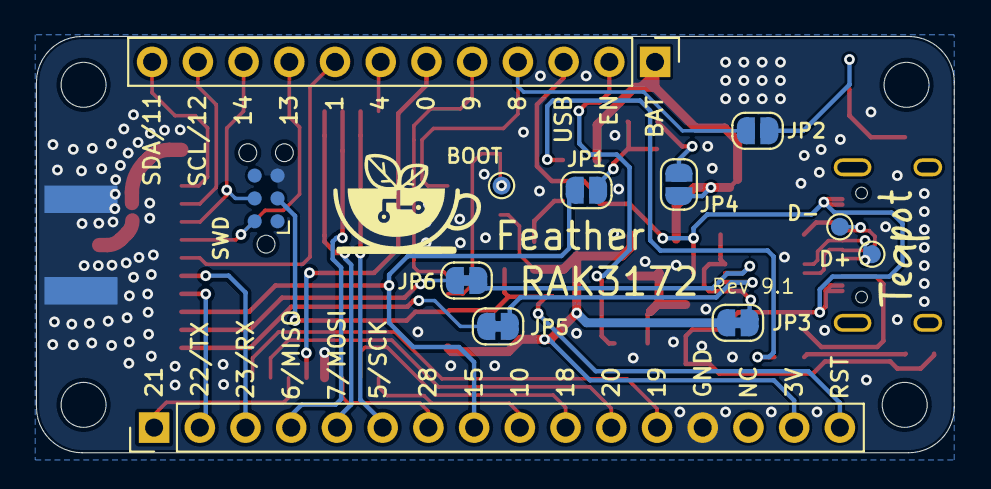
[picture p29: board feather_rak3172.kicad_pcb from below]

Board: 2 copper layers, 51.0 x 23.1 mm, 51 parts (12 on the bottom side), 47 nets.

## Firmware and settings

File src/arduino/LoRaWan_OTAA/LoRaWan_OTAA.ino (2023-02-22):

#define OTAA_PERIOD   (20000)
/*************************************

   LoRaWAN band setting:
     RAK_REGION_EU433
     RAK_REGION_CN470
     RAK_REGION_RU864
     RAK_REGION_IN865
     RAK_REGION_EU868
     RAK_REGION_US915
     RAK_REGION_AU915
     RAK_REGION_KR920
     RAK_REGION_AS923

 *************************************/
#define OTAA_BAND     (RAK_REGION_US915)
#define OTAA_DEVEUI   {0xAC, 0x1F, 0x09, 0xFF, 0xFE, 0x08, 0x33, 0x9B} // AC1F09FFFE08339B
#define OTAA_APPEUI   {0x0E, 0x0D, 0x0D, 0x01, 0x0E, 0x01, 0x02, 0x0E} // 0E0D0D010E01020E
#define OTAA_APPKEY   {0x3d, 0xbe, 0x8c, 0xc0, 0x87, 0x77, 0x5c, 0x9e, 0x83, 0xba, 0x7c, 0x5e, 0x9a, 0x88, 0x96, 0x98} // 3dbe8cc087775c9e83ba7c5e9a889698

/** Packet buffer for sending */
uint8_t collected_data[64] = { 0 };

void recvCallback(SERVICE_LORA_RECEIVE_T * data)
{
  if (data->BufferSize > 0) {
    Serial.println("Something received!");
    for (int i = 0; i < data->BufferSize; i++) {
      Serial.printf("%x", data->Buffer[i]);
    }
    Serial.print("\r\n");
  }
}

void joinCallback(int32_t status)
{
  Serial.printf("Join status: %d\r\n", status);
}

void sendCallback(int32_t status)
{
  if (status == 0) {
    Serial.println("Successfully sent");
  } else {
    Serial.println("Sending failed");
  }
}

void setup()
{
  Serial.begin(115200, RAK_AT_MODE);

  Serial.println("RAKwireless LoRaWan OTAA Example");
  Serial.println("------------------------------------------------------");

  // OTAA Device EUI MSB first
  uint8_t node_device_eui[8] = OTAA_DEVEUI;
  // OTAA Application EUI MSB first
  uint8_t node_app_eui[8] = OTAA_APPEUI;
  // OTAA Application Key MSB first
  uint8_t node_app_key[16] = OTAA_APPKEY;

  if (!api.lorawan.appeui.set(node_app_eui, 8)) {
    Serial.printf("LoRaWan OTAA - set application EUI is incorrect! \r\n");
    return;
  }
  if (!api.lorawan.appkey.set(node_app_key, 16)) {
    Serial.printf("LoRaWan OTAA - set application key is incorrect! \r\n");
    return;
  }
  if (!api.lorawan.deui.set(node_device_eui, 8)) {
    Serial.printf("LoRaWan OTAA - set device EUI is incorrect! \r\n");
    return;
  }

  if (!api.lorawan.band.set(OTAA_BAND)) {
    Serial.printf("LoRaWan OTAA - set band is incorrect! \r\n");
    return;
  }
  if (!api.lorawan.deviceClass.set(RAK_LORA_CLASS_A)) {
    Serial.printf("LoRaWan OTAA - set device class is incorrect! \r\n");
    return;
  }
  if (!api.lorawan.njm.set(RAK_LORA_OTAA))	// Set the network join mode to OTAA
  {
    Serial.
	printf("LoRaWan OTAA - set network join mode is incorrect! \r\n");
    return;
  }
  if (!api.lorawan.join())	// Join to Gateway
  {
    Serial.printf("LoRaWan OTAA - join fail! \r\n");
    return;
  }

  /** Wait for Join success */
  while (api.lorawan.njs.get() == 0) {
    Serial.print("Wait for LoRaWAN join...");
    api.lorawan.join();
    delay(10000);
  }

  if (!api.lorawan.adr.set(true)) {
    Serial.printf
	("LoRaWan OTAA - set adaptive data rate is incorrect! \r\n");
    return;
  }
  if (!api.lorawan.rety.set(1)) {
    Serial.printf("LoRaWan OTAA - set retry times is incorrect! \r\n");
    return;
  }
  if (!api.lorawan.cfm.set(1)) {
    Serial.printf("LoRaWan OTAA - set confirm mode is incorrect! \r\n");
    return;
  }

  /** Check LoRaWan Status*/
  Serial.printf("Duty cycle is %s\r\n", api.lorawan.dcs.get()? "ON" : "OFF");	// Check Duty Cycle status
  Serial.printf("Packet is %s\r\n", api.lorawan.cfm.get()? "CONFIRMED" : "UNCONFIRMED");	// Check Confirm status
  uint8_t assigned_dev_addr[4] = { 0 };
  api.lorawan.daddr.get(assigned_dev_addr, 4);
  Serial.printf("Device Address is %02X%02X%02X%02X\r\n", assigned_dev_addr[0], assigned_dev_addr[1], assigned_dev_addr[2], assigned_dev_addr[3]);	// Check Device Address
  Serial.printf("Uplink period is %ums\r\n", OTAA_PERIOD);
  Serial.println("");
  api.lorawan.registerRecvCallback(recvCallback);
  api.lorawan.registerJoinCallback(joinCallback);
  api.lorawan.registerSendCallback(sendCallback);
}

void uplink_routine()
{
  /** Payload of Uplink */
  uint8_t data_len = 0;
  collected_data[data_len++] = (uint8_t) 't';
  collected_data[data_len++] = (uint8_t) 'e';
  collected_data[data_len++] = (uint8_t) 's';
  collected_data[data_len++] = (uint8_t) 't';

  Serial.println("Data Packet:");
  for (int i = 0; i < data_len; i++) {
    Serial.printf("0x%02X ", collected_data[i]);
  }
  Serial.println("");

  /** Send the data package */
  if (api.lorawan.send(data_len, (uint8_t *) & collected_data, 2, true, 1)) {
    Serial.println("Sending is requested");
  } else {
    Serial.println("Sending failed");
  }
}

void loop()
{
  static uint64_t last = 0;
  static uint64_t elapsed;

  if ((elapsed = millis() - last) > OTAA_PERIOD) {
    uplink_routine();

    last = millis();
  }
  //Serial.printf("Try sleep %ums..", OTAA_PERIOD);
  api.system.sleep.all(OTAA_PERIOD);
  //Serial.println("Wakeup..");
}

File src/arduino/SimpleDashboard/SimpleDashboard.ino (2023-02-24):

#include <LOLIN_EPD.h>
#include <Adafruit_GFX.h>
#include "Application.h"

#define EPD_CS    PA4
#define EPD_DC    PA0 
#define EPD_RST   -1  // can set to -1 and share with microcontroller Reset!
#define EPD_BUSY  -1  // can set to -1 to not use a pin (will wait a fixed delay)

LOLIN_SSD1680 display(250, 122, EPD_DC, EPD_RST, EPD_CS, EPD_BUSY); //hardware SPI

teapot::Application app;
teapot::SensorData data;
int hour;
int minute;

void setup() {
  
  api.system.restoreDefault();
  Serial.begin(115200);
  Serial.println("    Simple Dashboard   ");
  Serial.println("-----------------------");

  // initialze app
  app.Initialize();
  if( app.ConfigureSensor() != teapot::ReturnCode::kOk )
  {
    Serial.println("failed to configure sensor");
    while(true) delay( 1000 );
  }
  delay( 500 );

  // blink at boot
  app.EnableLed( true );  
  delay(500);  
  app.EnableLed( false );
  
  display.begin();
}

void loop() {
  app.ResetGnssData();
  
  // power-on peripherals
  app.EnablePeripheral( true );
  app.EnableGnss( true );
  
  Serial.println("Fetching Data and Updating Screen");
  if ( app.GetSensorData(data) != teapot::ReturnCode::kOk ) 
  {
    Serial.println("Failed to perform reading BME680");
    /* power-off peripherals */
    app.EnableGnss( false );
    app.EnablePeripheral( false );
  }
  else
  {
    // get time
    teapot::ReturnCode ret = app.ProcessGnssStream(5, 1, 60 * 1000);    
    Serial.printf("process gnss stream done. err: %d\r\n", ret);
    Serial.printf("hdop: %f, sat: %d, lat: %f, long: %f\r\n", 
                  app.GetGnssData().hdop.hdop(), 
                  app.GetGnssData().satellites.value(),
                  app.GetGnssData().location.lat(),
                  app.GetGnssData().location.lng());
                  
    /* power-off peripherals */
    app.EnableGnss( false );
    app.EnablePeripheral( false );
    
    Serial.print("Temperature = ");
    Serial.print(data.temperature);
    Serial.println(" *C");
  
    Serial.print("Humidity = ");
    Serial.print(data.humidity);
    Serial.println(" %");
  
    Serial.print("Battery Voltage = ");
    Serial.print(app.ReadBatteryVoltage());
    Serial.println(" V");

    Serial.print("Current Time = ");
    Serial.print(app.GetGnssData().time.hour());
    Serial.print(":");
    Serial.println(app.GetGnssData().time.minute());

    // convert time to local time
    hour = app.GetGnssData().time.hour();
    int utc_to_local = -8; // utc to GMT-8
    int local_hour = hour + utc_to_local;
    hour = (local_hour < 0) ? 24 + local_hour : local_hour;
    minute = app.GetGnssData().time.minute();
    Serial.print("Current Local Time = ");
    Serial.print(hour);
    Serial.print(":");
    Serial.println(minute);

    /* write frame buffer */
    display.clearBuffer();
    display.setTextSize(2);
    display.setTextColor(EPD_BLACK);
    display.setCursor(3, 0);
    display.print(data.temperature,1);
    display.setTextColor(EPD_RED);
    display.print("C");
  
    display.setTextColor(EPD_BLACK);
    display.setCursor(100, 0);
    display.print(data.humidity,1);
    display.setTextColor(EPD_RED);
    display.print("%");
  
    display.setTextColor(EPD_BLACK);
    display.setCursor(190, 0);
    display.print(app.ReadBatteryVoltage(), 2);
    display.setTextColor(EPD_RED);
    display.print("V");
  
    display.setTextSize(3);
    display.setCursor( ((display.width() - 144)/2) - 20, (display.height() - 24)/2);
    display.setTextColor(EPD_RED);
    display.print("Time ");
    display.setTextColor(EPD_BLACK);
    if(hour < 10)
    {
        display.print("0");
    }
    display.print(hour);
    display.print(":");
    if(minute < 10)
    {
        display.print("0");
    }
    display.print(minute);
    
    
    display.setTextSize(2);
    display.setTextColor(EPD_BLACK);
    display.setCursor(3, display.height() - 20);
    display.print(app.GetGnssData().satellites.value());
    display.setTextColor(EPD_RED);
    display.print("Sat");
  
    display.setTextSize(2);
    display.setTextColor(EPD_BLACK);
    display.setCursor(165, display.height() - 20);
    float hdop = app.GetGnssData().hdop.hdop();
    if( hdop > 99 )
      {
        hdop = 0.00; 
      }
    display.print(hdop, 1);
    display.setTextColor(EPD_RED);
    display.print("HDOP");    
    /* end of write frame buffer */
    
    display.display();
  }

  api.system.sleep.all(5 * 60 * 1000);
}

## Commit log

2022-12-25 add feather template
    [feather_rak3172.kicad_pcb, feather_rak3172.kicad_sch]
2022-12-28 initial board design
    [feather_rak3172.kicad_pcb, feather_rak3172.kicad_sch]
2022-12-29 push initial board layout
    [feather_rak3172.kicad_pcb, feather_rak3172.kicad_sch]
2022-12-31 initial completed wiring
    [feather_rak3172.kicad_pcb, feather_rak3172.kicad_sch]
2022-12-31 add additional graphics
    [feather_rak3172.kicad_pcb]
2022-12-31 add revision
    [feather_rak3172.kicad_pcb, feather_rak3172.kicad_sch]
2023-01-02 add impedance matching circuit and jumper to disable ch340, voltage divider
    [feather_rak3172.kicad_pcb, feather_rak3172.kicad_sch]
2023-01-07 breakout D+ and D-, fix incorrect ch340e power wiring, add minor comments
    [feather_rak3172.kicad_pcb, feather_rak3172.kicad_sch]
2023-01-07 add more ground stiching
    [feather_rak3172.kicad_pcb]
2023-01-18 reduce text thickness
    [feather_rak3172.kicad_pcb]
2023-01-18 update 3d model path
    [feather_rak3172.kicad_pcb]
2023-01-18 slightly align RF trace with matching circuit
    [feather_rak3172.kicad_pcb]
2023-01-19 remove unnecessary ground pour
    [feather_rak3172.kicad_pcb, feather_rak3172.kicad_sch]
2023-01-19 revision 4
    [feather_rak3172.kicad_pcb, feather_rak3172.kicad_sch]
2023-01-20 minor trace changes
    [feather_rak3172.kicad_pcb]
2023-01-20 minor traces adjustment
    [feather_rak3172.kicad_pcb]
2023-01-24 minor trace adjustment
    [feather_rak3172.kicad_pcb]
2023-01-25 add component description and minor footprint changes
    [feather_rak3172.kicad_pcb, feather_rak3172.kicad_sch]
2023-02-07 remove usb-c shield ground connection
    [feather_rak3172.kicad_pcb, feather_rak3172.kicad_sch]
2023-02-07 move capacitor closer to charger chip
    [feather_rak3172.kicad_pcb, feather_rak3172.kicad_sch]
2023-02-07 minor cosmetic changes
    [feather_rak3172.kicad_sch]
2023-02-07 revision 5
    [feather_rak3172.kicad_pcb, feather_rak3172.kicad_sch]
2023-02-11 remove matching circuit, trace too short
    [feather_rak3172.kicad_pcb, feather_rak3172.kicad_sch]
2023-02-11 re-add matching circuit, improve rf trace angle
    [feather_rak3172.kicad_pcb, feather_rak3172.kicad_sch]
2023-02-20 remove 3v3 signal from swd pinout
    [feather_rak3172.kicad_pcb, feather_rak3172.kicad_sch]
2023-02-20 remove gnd via under antenna port
    [feather_rak3172.kicad_pcb]
2023-02-20 change antenna part number
    [feather_rak3172.kicad_sch]
2023-02-20 add extra trace to batt pin out
    [feather_rak3172.kicad_pcb]
2023-02-22 add solder jump for txd and rxd, minor silkscreen changes
    [feather_rak3172.kicad_pcb, feather_rak3172.kicad_sch]
2023-02-22 minor silkscreen changes
    [feather_rak3172.kicad_pcb]
2023-02-22 update revision number to 8.1
    [feather_rak3172.kicad_pcb, feather_rak3172.kicad_sch]
2023-02-24 add epd driver from lolin
2023-02-24 update example code
    [Configuration.h]
2023-03-21 change solder jump to open, and minor component description changes
    [feather_rak3172.kicad_pcb, feather_rak3172.kicad_sch]
2023-03-21 update silkscreen version, and minor sch and silkscreen changes
    [feather_rak3172.kicad_pcb, feather_rak3172.kicad_sch]
2023-03-21 minor schematic unit changes
    [feather_rak3172.kicad_pcb, feather_rak3172.kicad_sch]
2023-03-21 change sma connector to through-hole type
    [feather_rak3172.kicad_pcb]
2023-03-21 fix components position
    [feather_rak3172.kicad_pcb, feather_rak3172.kicad_sch]
2023-03-22 change boot button to 3v3
    [feather_rak3172.kicad_pcb, feather_rak3172.kicad_sch]
2023-03-22 minor schematic changes
    [feather_rak3172.kicad_sch]
2023-04-23 add documentation files
    [assembeld_board.stl, bottom.stl, top.stl]
2023-04-26 add assembly file
    [TeapotFeatherRAK3172_BOM.csv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]
2023-04-26 add bill of materials
    [bill_of_materials.csv]
2023-05-22 fix D1 polarity
    [feather_rak3172.kicad_pcb, feather_rak3172.kicad_sch]
2023-05-22 update revision version to 9.1
    [feather_rak3172.kicad_pcb, feather_rak3172.kicad_sch]
2023-05-22 update gerber file to rev 9.1

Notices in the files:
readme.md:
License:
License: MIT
